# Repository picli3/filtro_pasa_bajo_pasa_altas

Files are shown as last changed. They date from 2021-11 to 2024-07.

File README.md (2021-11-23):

# Filtro pasa medios y pasa altos

Este filtro aun esta en proceso de desarrollo, no me hago responsable de algunos problemas ocacionados, estare subiendo aca los vanaces hasta cerrar el proyecto, eres libre de copiar el proyecto y modificarlo siempre y cuando hagas mension del origen de la informacion.

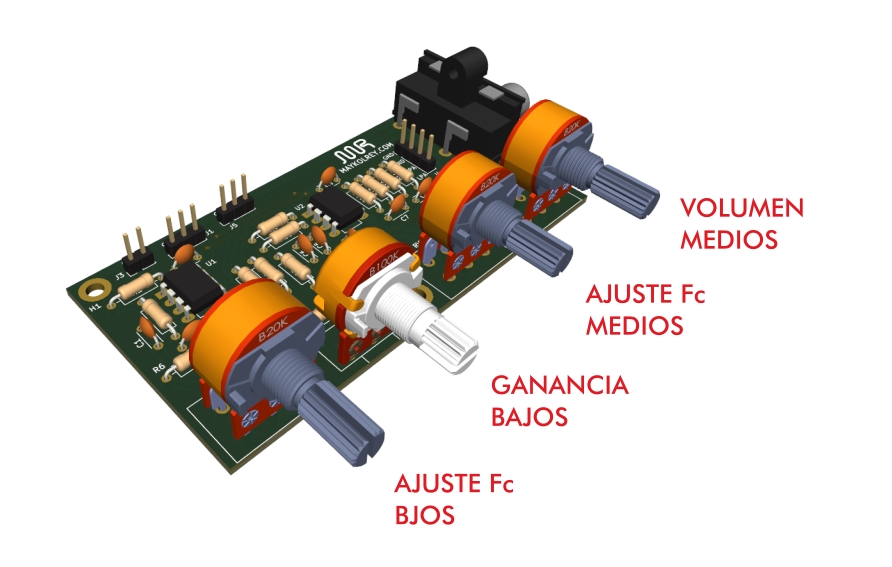
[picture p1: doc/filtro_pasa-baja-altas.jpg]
filtro pasa alta pasa baja filtro

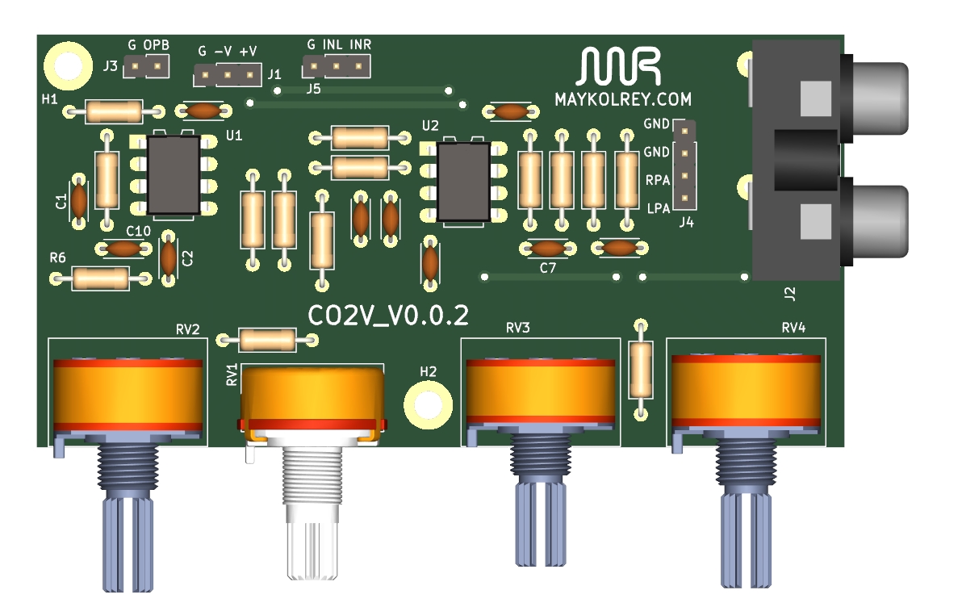
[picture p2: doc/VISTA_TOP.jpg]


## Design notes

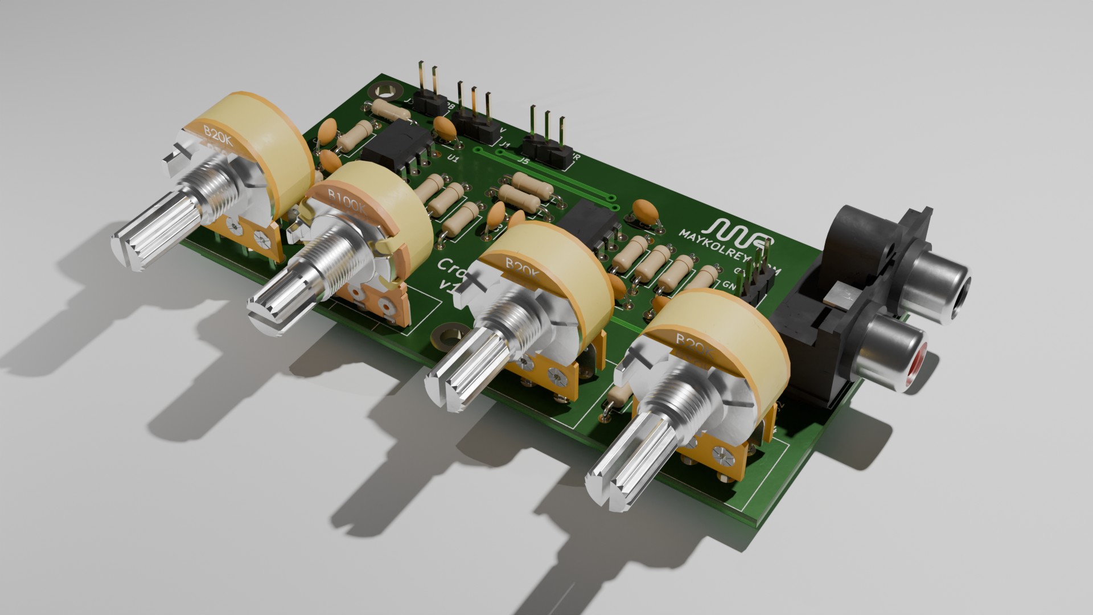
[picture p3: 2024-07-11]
iso.jpg

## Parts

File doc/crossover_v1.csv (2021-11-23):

Item | Qty | Reference(s) | Value | LibPart | Footprint
1 | 6 | C1, C2, C5, C6, C7, C8 | 47nF | Device:C | Capacitor_THT:C_Disc_D4.3mm_W1.9mm_P5.00mm
2 | 4 | C3, C4, C9, C10 | 100nF | Device:C | Capacitor_THT:C_Disc_D4.3mm_W1.9mm_P5.00mm
3 | 2 | H1, H2 | MountingHole | Mechanical:MountingHole | MountingHole:MountingHole_3.2mm_M3_DIN965_Pad
4 | 1 | J1 | POWER | Connector_Generic:Conn_01x03 | Connector_PinHeader_2.54mm:PinHeader_1x03_P2.54mm_Vertical
5 | 1 | J2 | IN | Connector:Conn_Coaxial_x2 | MSS_Connector:CUI_RCJ-21XX
6 | 1 | J3 | OUT | Connector:Conn_01x02_Male | Connector_PinHeader_2.54mm:PinHeader_1x02_P2.54mm_Vertical
7 | 1 | J4 | OUT | Connector:Conn_01x04_Male | Connector_PinHeader_2.54mm:PinHeader_1x04_P2.54mm_Vertical
8 | 1 | J5 | OUT | Connector:Conn_01x03_Male | Connector_PinHeader_2.54mm:PinHeader_1x03_P2.54mm_Vertical
9 | 1 | R1 | 2.7K | Device:R | Resistor_THT:R_Axial_DIN0207_L6.3mm_D2.5mm_P10.16mm_Horizontal
10 | 1 | R2 | 4.7K | Device:R | Resistor_THT:R_Axial_DIN0207_L6.3mm_D2.5mm_P10.16mm_Horizontal
11 | 2 | R3, R4 | 22K | Device:R | Resistor_THT:R_Axial_DIN0207_L6.3mm_D2.5mm_P10.16mm_Horizontal
12 | 4 | R5, R6, R10, R14 | 10K | Device:R | Resistor_THT:R_Axial_DIN0207_L6.3mm_D2.5mm_P10.16mm_Horizontal
13 | 2 | R7, R11 | 1K | Device:R | Resistor_THT:R_Axial_DIN0207_L6.3mm_D2.5mm_P10.16mm_Horizontal
14 | 2 | R8, R12 | 2K | Device:R | Resistor_THT:R_Axial_DIN0207_L6.3mm_D2.5mm_P10.16mm_Horizontal
15 | 2 | R9, R13 | 18K | Device:R | Resistor_THT:R_Axial_DIN0207_L6.3mm_D2.5mm_P10.16mm_Horizontal
16 | 1 | RV1 | 47K | Device:R_Potentiometer | Potentiometer_THT:Potentiometer_Piher_T-16H_Single_Horizontal
17 | 1 | RV2 | 100K | Device:R_Potentiometer_Dual | Potentiometer_THT:Potentiometer_Alps_RK163_Dual_Horizontal
18 | 2 | RV3, RV4 | 5K | Device:R_Potentiometer_Dual | Potentiometer_THT:Potentiometer_Alps_RK163_Dual_Horizontal
19 | 2 | U1, U2 | TL082 | MSS_Operational-Amplifier:TL082 | Package_DIP:DIP-8_W7.62mm_LongPads

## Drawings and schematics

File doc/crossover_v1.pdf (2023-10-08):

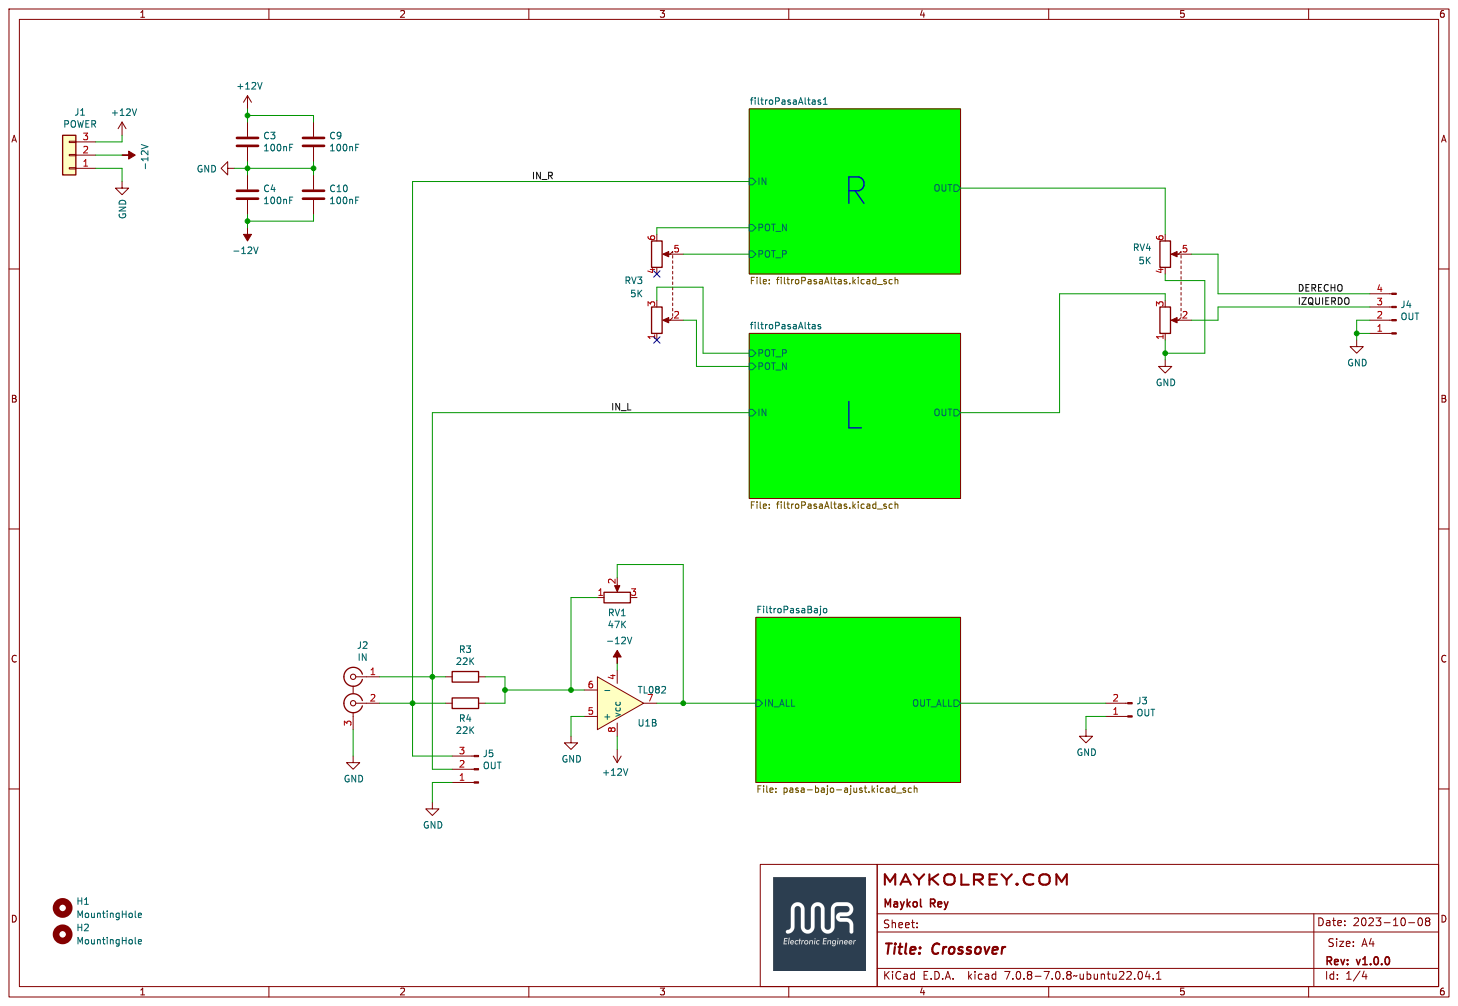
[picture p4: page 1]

MAYKOLREY.COM

Rey | Id: 1/4 Title: Crossover Sheet: Maykol

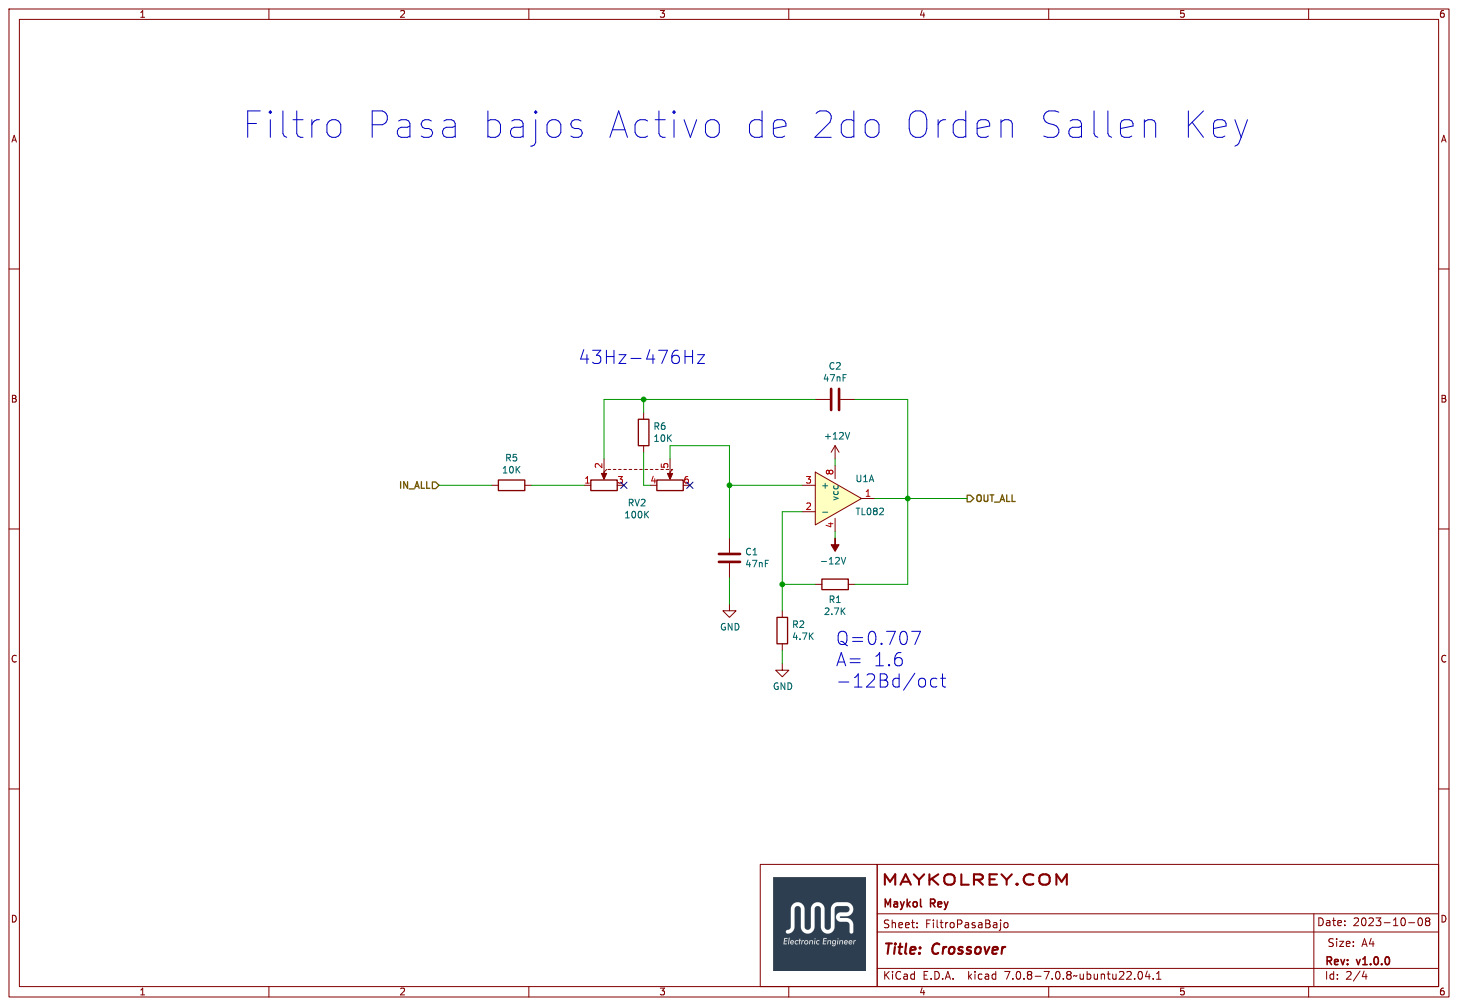
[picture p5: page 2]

Id: 2/4 Title: Crossover Sheet: FiltroPasaBajo

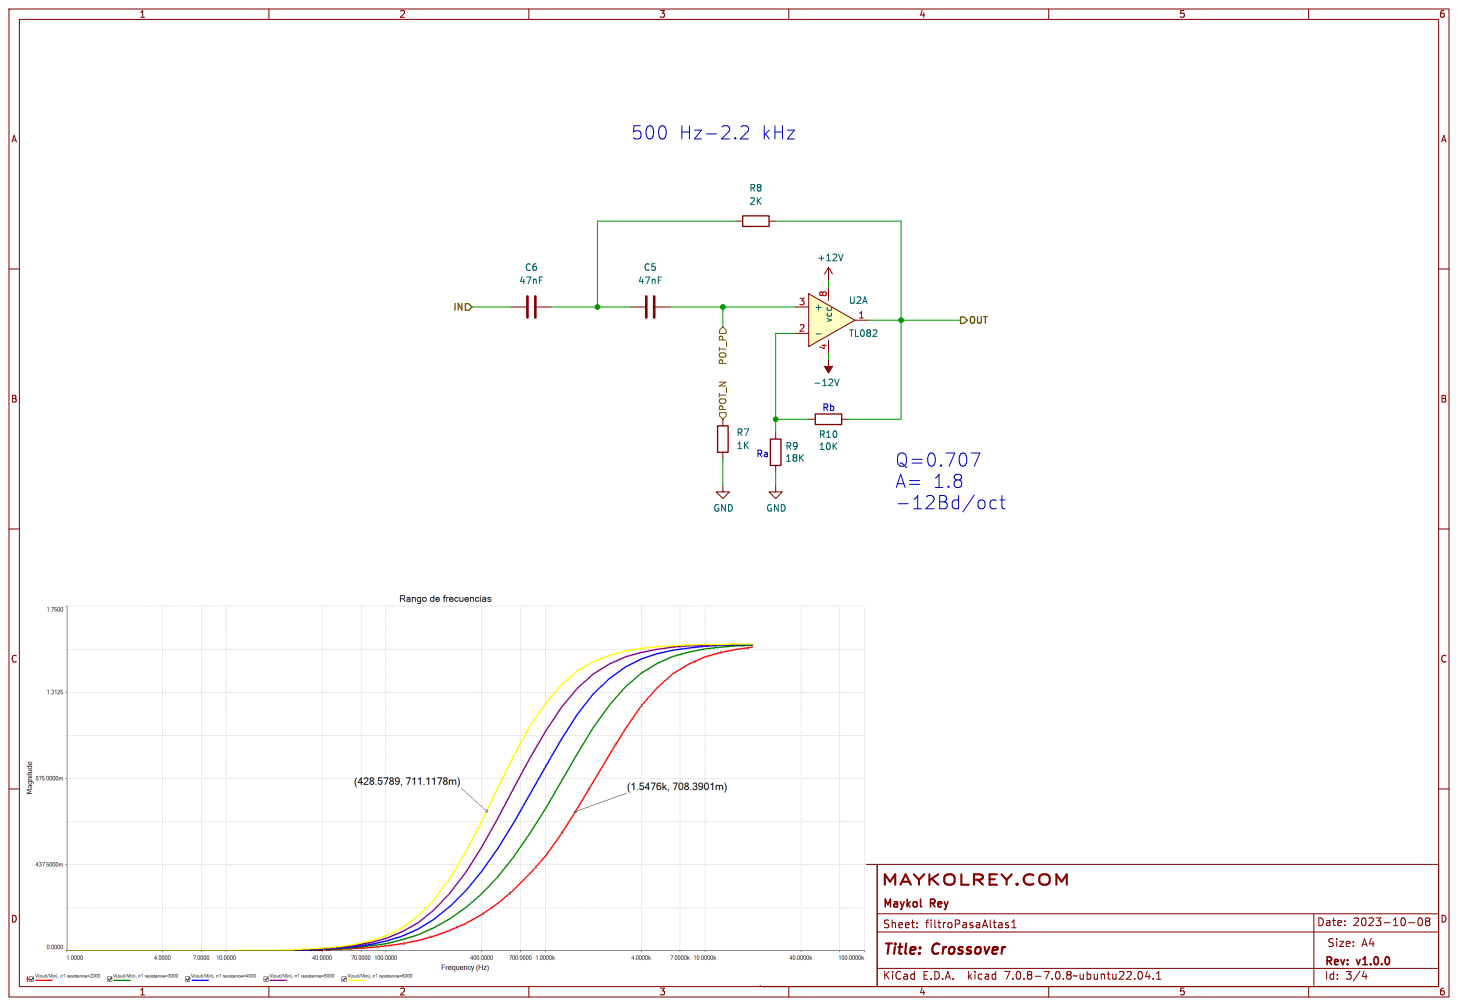
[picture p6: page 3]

MAYKOLREY.COM

Rey | Id: 3/4 Title: Crossover Sheet: filtroPasaAltas1 Maykol

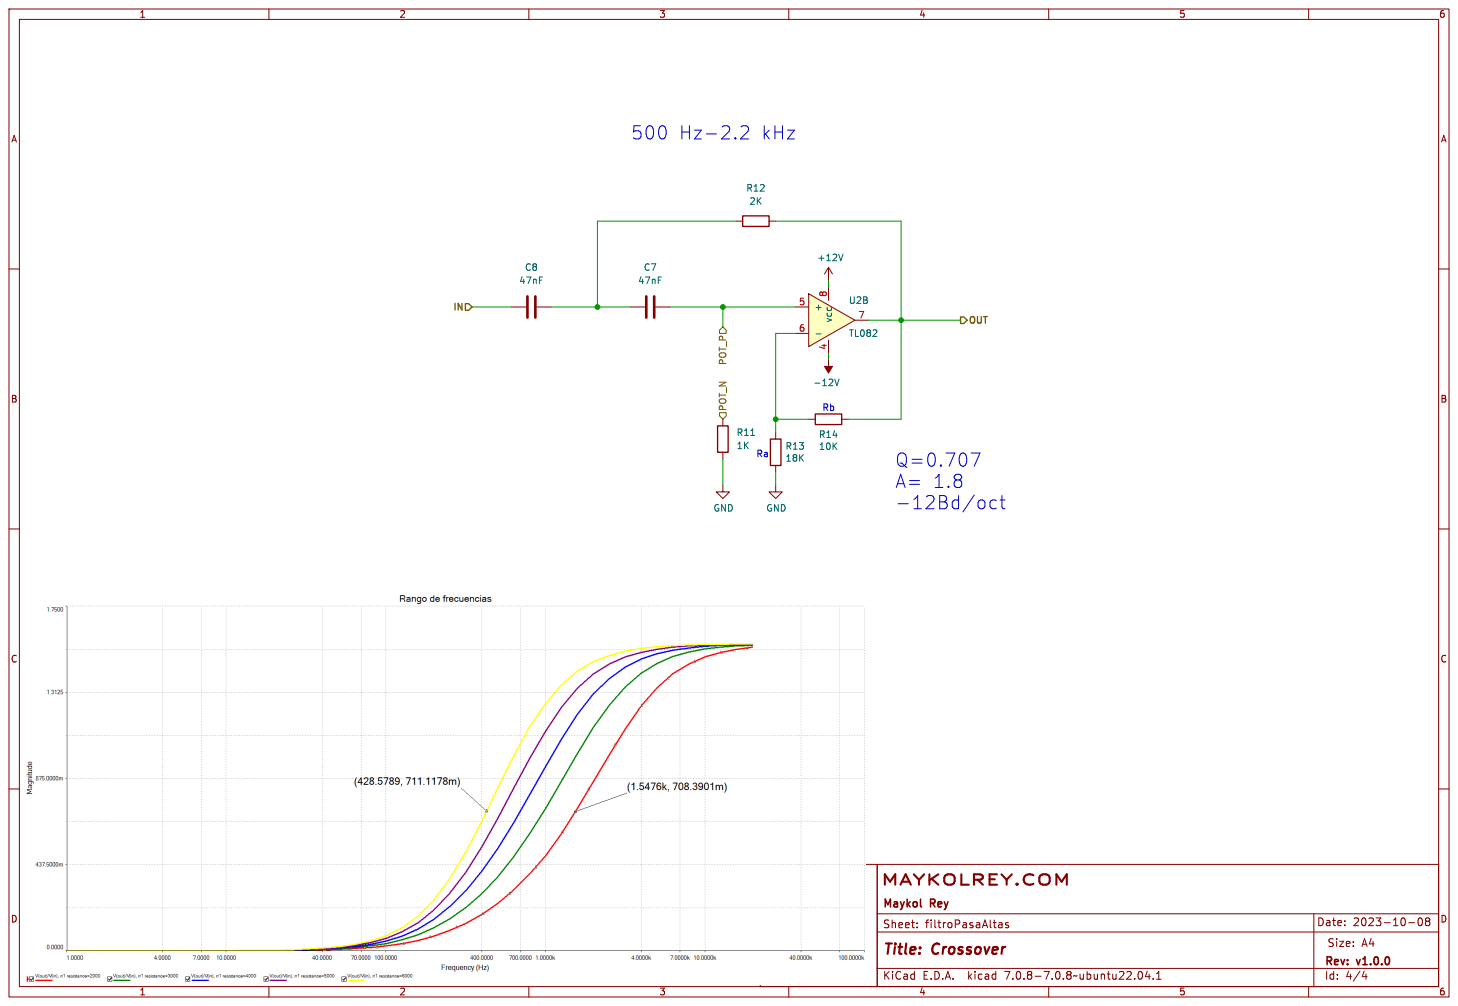
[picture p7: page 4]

MAYKOLREY.COM

Rey | Id: 4/4 Title: Crossover Sheet: filtroPasaAltas Maykol

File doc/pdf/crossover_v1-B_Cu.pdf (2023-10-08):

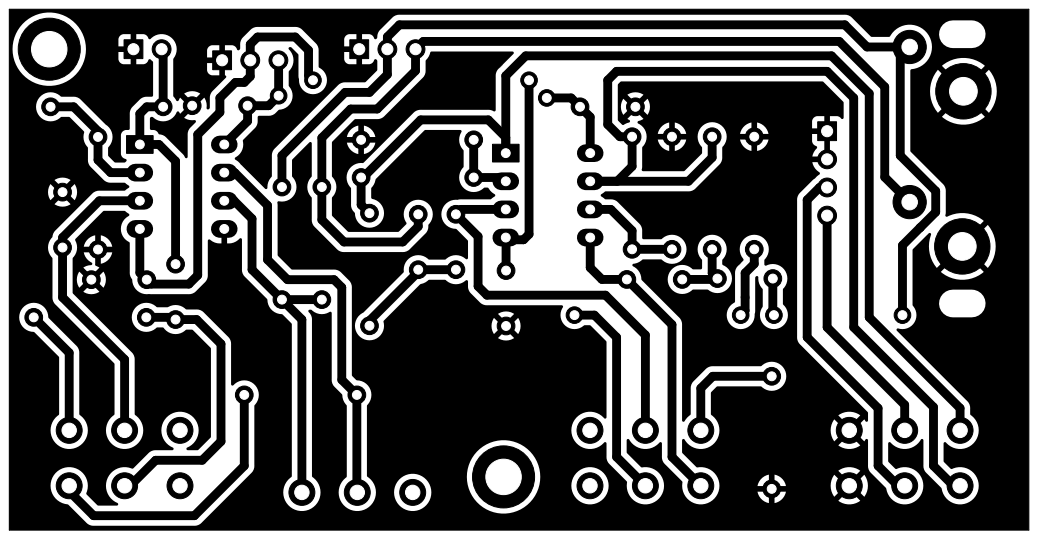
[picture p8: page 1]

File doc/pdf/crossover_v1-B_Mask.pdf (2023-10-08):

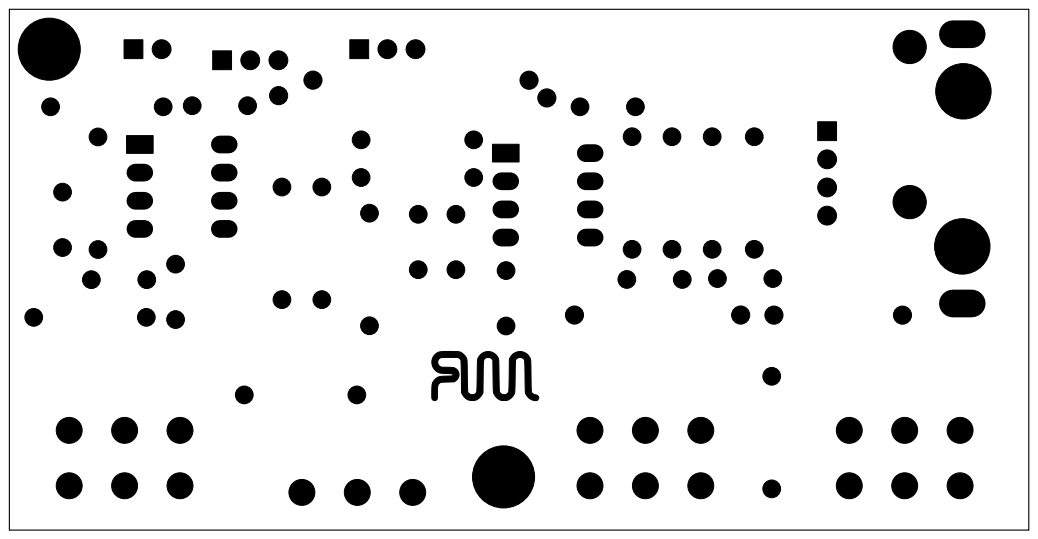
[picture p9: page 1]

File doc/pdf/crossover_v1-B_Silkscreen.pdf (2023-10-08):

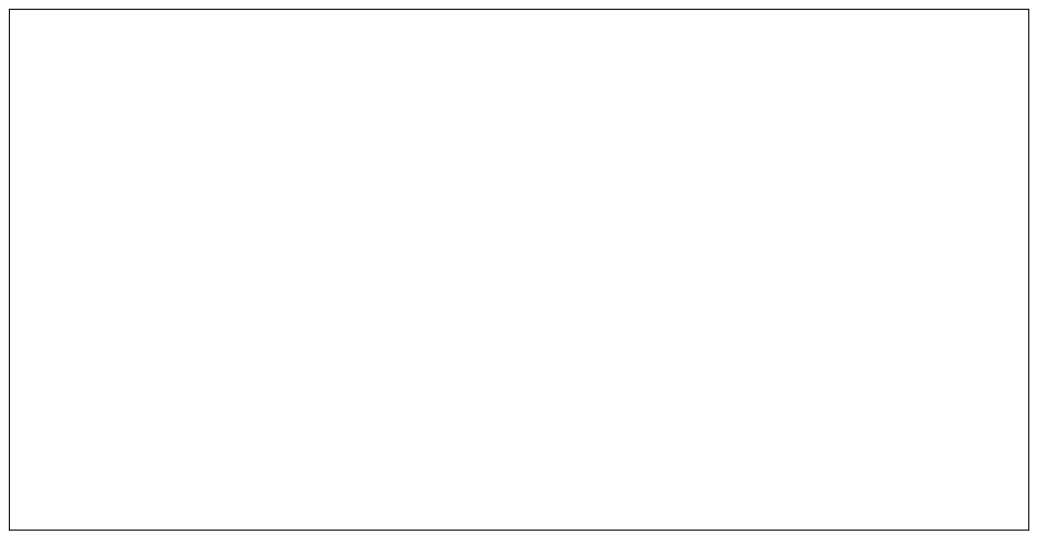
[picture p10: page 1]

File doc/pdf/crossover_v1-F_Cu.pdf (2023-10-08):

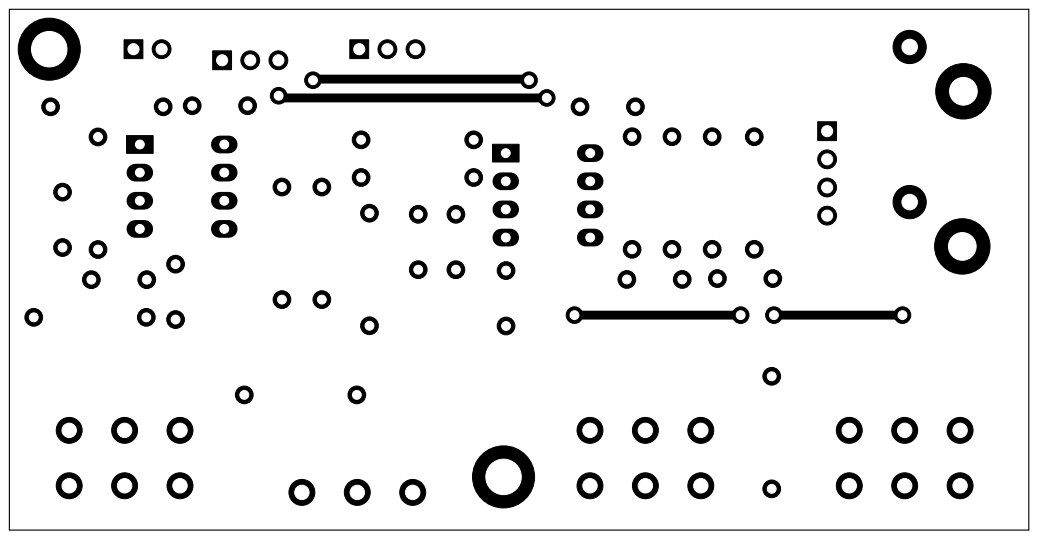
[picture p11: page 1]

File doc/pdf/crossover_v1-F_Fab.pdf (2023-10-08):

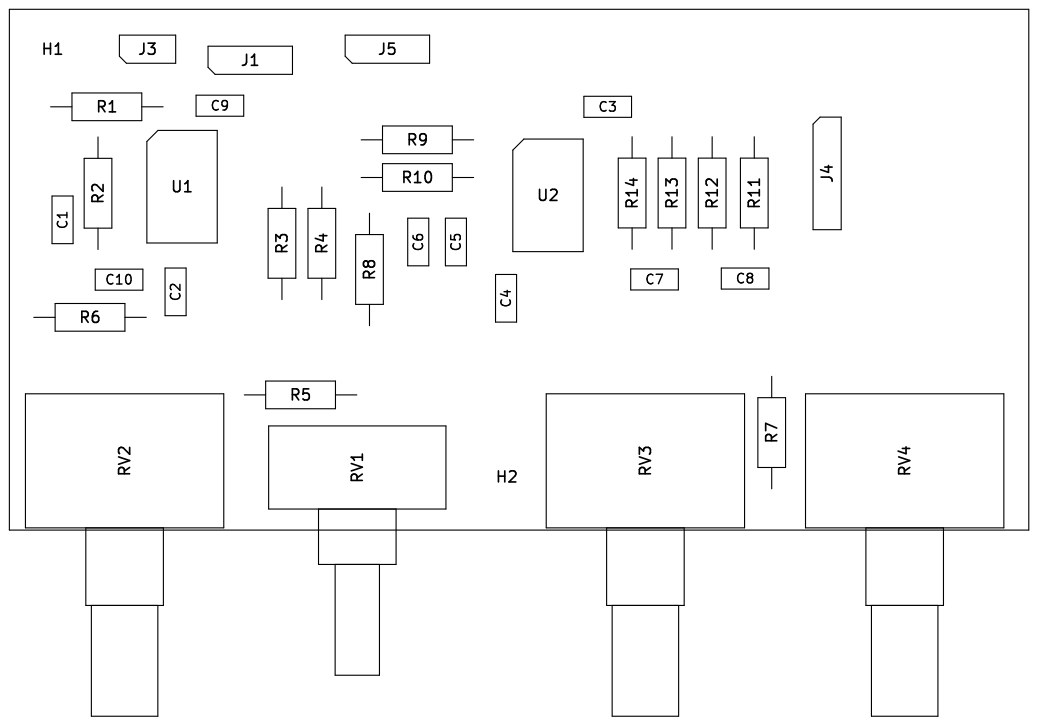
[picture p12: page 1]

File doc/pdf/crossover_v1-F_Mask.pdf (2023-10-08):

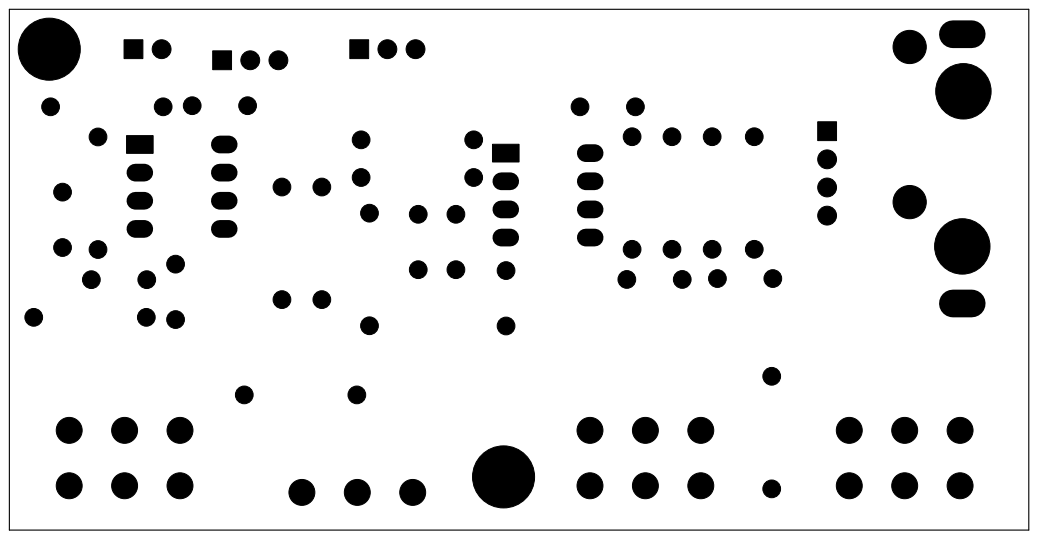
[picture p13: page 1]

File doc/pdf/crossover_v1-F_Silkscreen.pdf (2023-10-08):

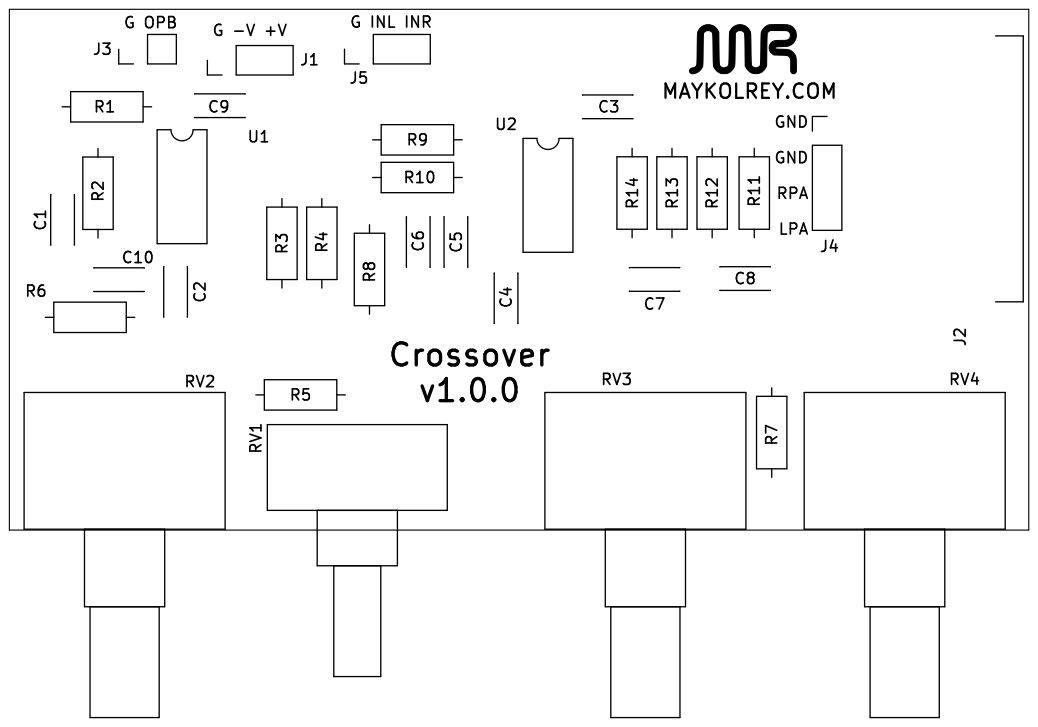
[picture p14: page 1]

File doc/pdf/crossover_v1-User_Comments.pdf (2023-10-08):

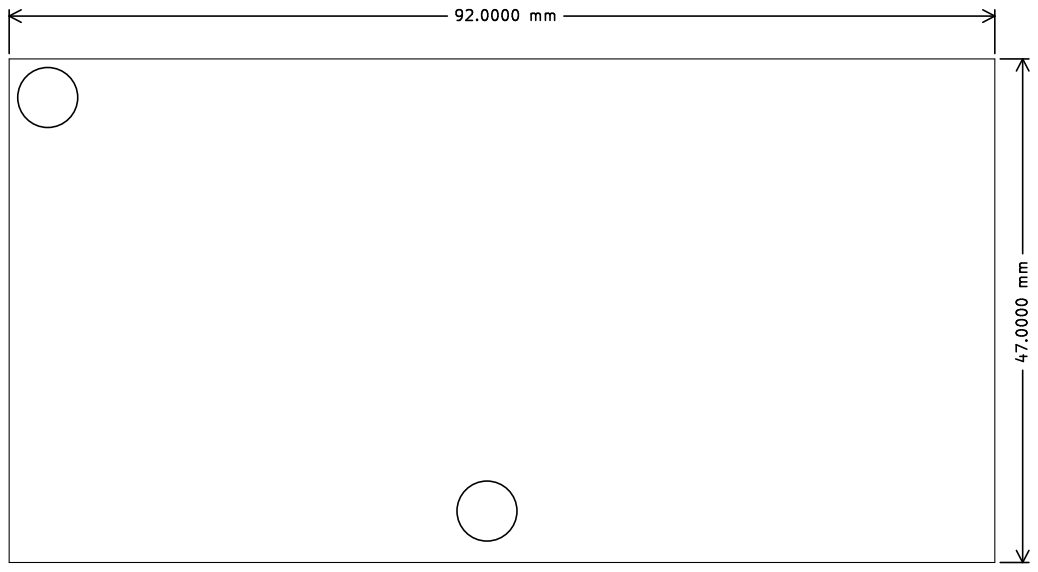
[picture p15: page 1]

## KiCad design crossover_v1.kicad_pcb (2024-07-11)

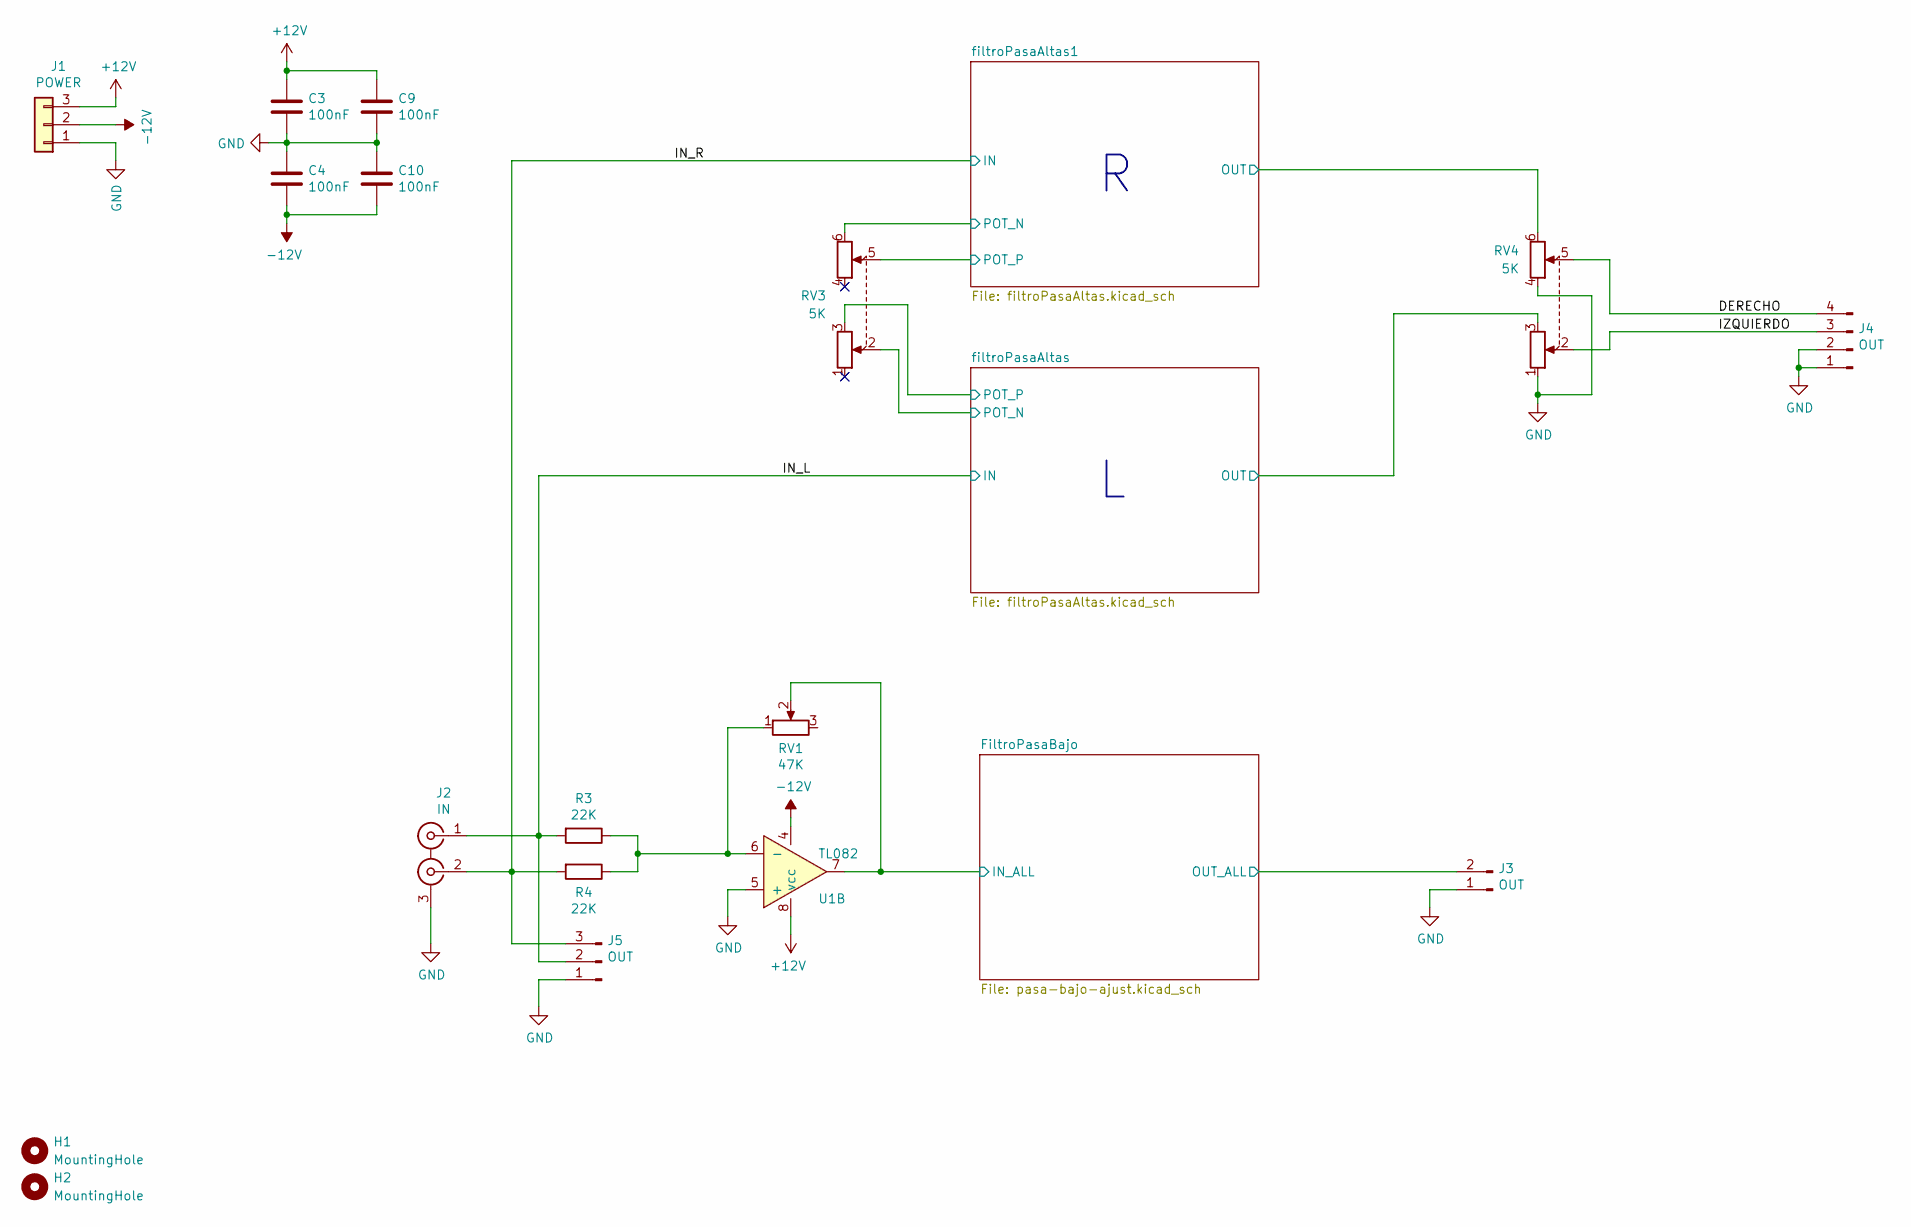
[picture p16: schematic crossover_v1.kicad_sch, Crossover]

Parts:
C3, C4, C9, C10: 100nF; C_Disc_D4.3mm_W1.9mm_P5.00mm
H1, H2: MountingHole; MountingHole_3.2mm_M3_DIN965_Pad
J1: POWER; PinHeader_1x03_P2.54mm_Vertical
J2: IN; CUI_RCJ-21XX
J3: OUT; PinHeader_1x02_P2.54mm_Vertical
J4: OUT; PinHeader_1x04_P2.54mm_Vertical
J5: OUT; PinHeader_1x03_P2.54mm_Vertical
R3, R4: 22K; R_Axial_DIN0207_L6.3mm_D2.5mm_P10.16mm_Horizontal
RV1: 47K; Potentiometer_Piher_T-16H_Single_Horizontal
RV3, RV4: 5K; Potentiometer_Alps_RK163_Dual_Horizontal
U1: TL082; DIP-8_W7.62mm_LongPads

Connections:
+12V: C3.2, C9.2, J1.3, U1.8 (vcc); also elsewhere on the board
-12V: C4.1, C10.1, J1.2, U1.4; also elsewhere on the board
/DERECHO: J4.4, RV4.5
/FiltroPasaBajo/IN_ALL: RV1.2, U1.7; also elsewhere on the board
/FiltroPasaBajo/OUT_ALL: J3.2; also elsewhere on the board
/IN_L: J2.1 (IN1), J5.2, R3.2; also elsewhere on the board
/IN_R: J2.2 (IN2), J5.3, R4.2; also elsewhere on the board
/IZQUIERDO: J4.3, RV4.2
/filtroPasaAltas1/OUT: RV4.6; also elsewhere on the board
/filtroPasaAltas1/POT_N: RV3.6; also elsewhere on the board
/filtroPasaAltas1/POT_P: RV3.5; also elsewhere on the board
/filtroPasaAltas/OUT: RV4.3; also elsewhere on the board
/filtroPasaAltas/POT_N: RV3.2; also elsewhere on the board
/filtroPasaAltas/POT_P: RV3.3; also elsewhere on the board
GND: C3.1, C4.2, C9.1, C10.2, J1.1, J2.3 (EXT), J3.1, J4.1, J4.2, J5.1, RV4.1, RV4.4, U1.5 (+); also elsewhere on the board
unnamed: R3.1, R4.1, RV1.1, U1.6 (-)

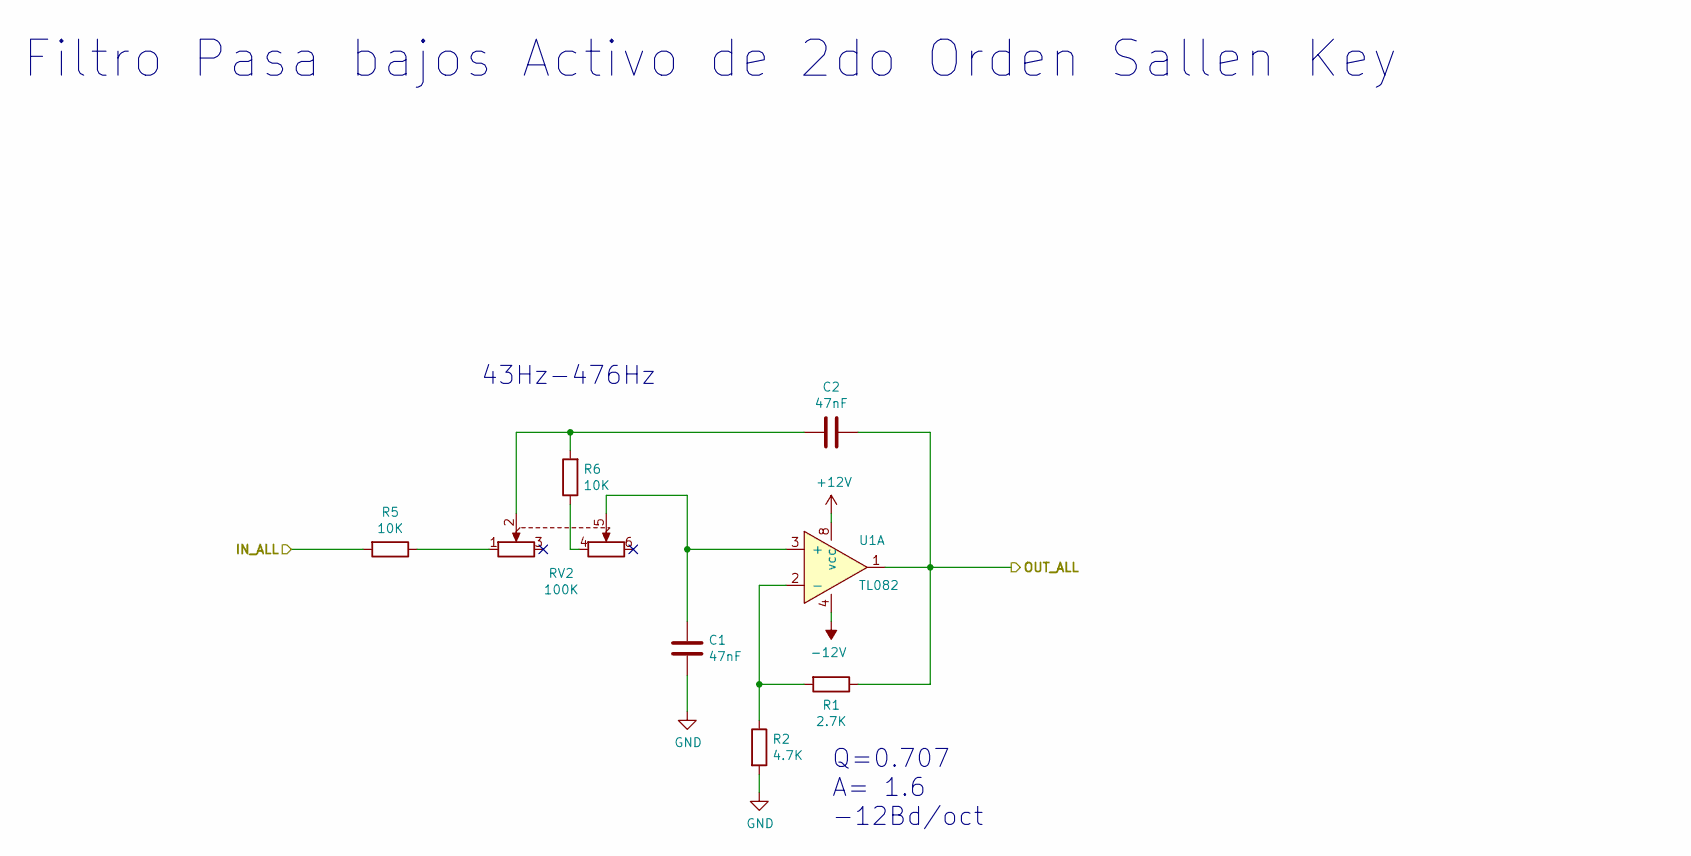
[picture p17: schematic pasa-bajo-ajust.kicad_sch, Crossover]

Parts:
C1, C2: 47nF; C_Disc_D4.3mm_W1.9mm_P5.00mm
R1: 2.7K; R_Axial_DIN0207_L6.3mm_D2.5mm_P10.16mm_Horizontal
R2: 4.7K; R_Axial_DIN0207_L6.3mm_D2.5mm_P10.16mm_Horizontal
R5, R6: 10K; R_Axial_DIN0207_L6.3mm_D2.5mm_P10.16mm_Horizontal
RV2: 100K; Potentiometer_Alps_RK163_Dual_Horizontal
U1: TL082; DIP-8_W7.62mm_LongPads

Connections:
+12V: U1.8 (vcc); also elsewhere on the board
-12V: U1.4; also elsewhere on the board
/FiltroPasaBajo/IN_ALL: R5.2; also elsewhere on the board
/FiltroPasaBajo/OUT_ALL: C2.1, R1.1, U1.1; also elsewhere on the board
GND: C1.1, R2.2; also elsewhere on the board
unnamed: C1.2, RV2.5, U1.3 (+)
unnamed: C2.2, R6.2, RV2.2
unnamed: R1.2, R2.1, U1.2 (-)
unnamed: R5.1, RV2.1
unnamed: R6.1, RV2.4

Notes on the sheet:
Filtro Pasa bajos Activo de 2do Orden Sallen Key
Q=0.707 A= 1.6 -12Bd/oct
43Hz-476Hz

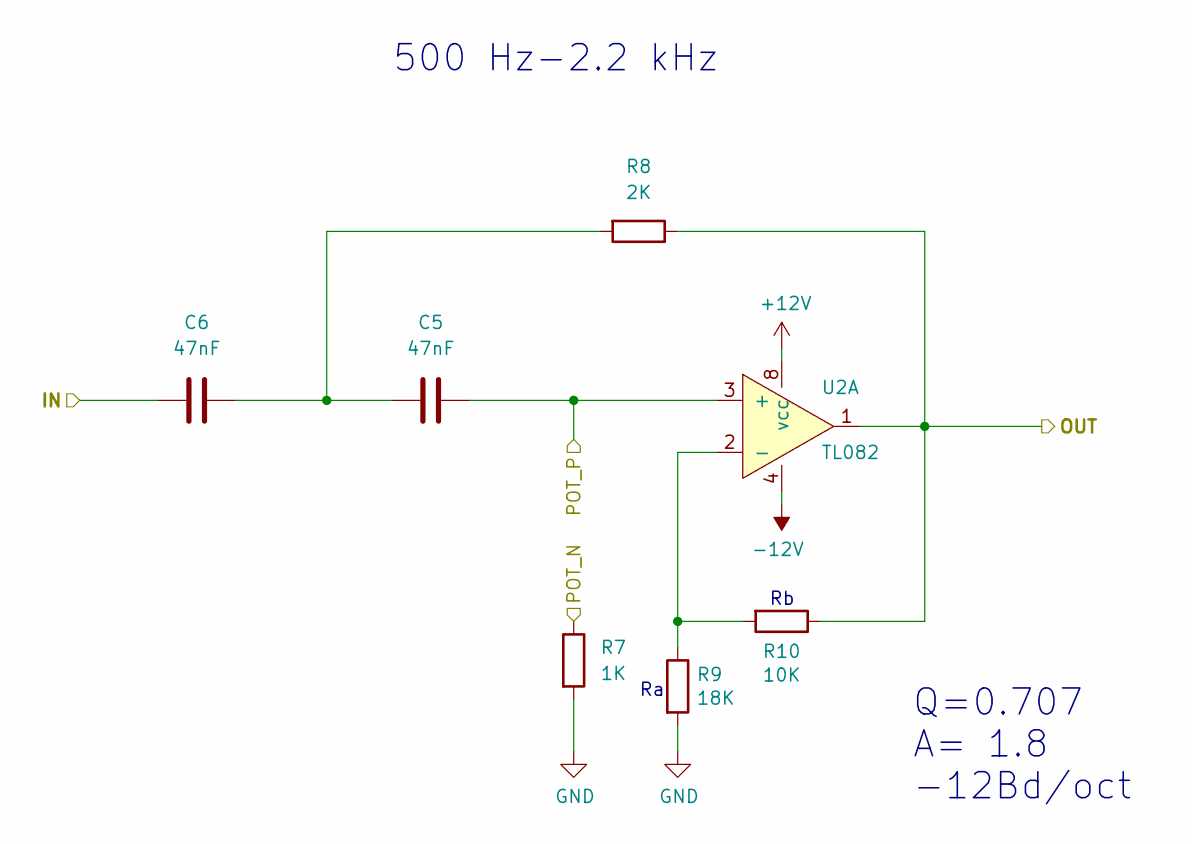
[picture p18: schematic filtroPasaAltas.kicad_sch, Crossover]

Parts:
C5, C6: 47nF; C_Disc_D4.3mm_W1.9mm_P5.00mm
R7: 1K; R_Axial_DIN0207_L6.3mm_D2.5mm_P10.16mm_Horizontal
R8: 2K; R_Axial_DIN0207_L6.3mm_D2.5mm_P10.16mm_Horizontal
R9: 18K; R_Axial_DIN0207_L6.3mm_D2.5mm_P10.16mm_Horizontal
R10: 10K; R_Axial_DIN0207_L6.3mm_D2.5mm_P10.16mm_Horizontal
U2: TL082; DIP-8_W7.62mm_LongPads

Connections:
+12V: U2.8 (vcc); also elsewhere on the board
-12V: U2.4; also elsewhere on the board
/IN_R: C6.2; also elsewhere on the board
/filtroPasaAltas1/OUT: R8.1, R10.1, U2.1; also elsewhere on the board
/filtroPasaAltas1/POT_N: R7.1; also elsewhere on the board
/filtroPasaAltas1/POT_P: C5.1, U2.3 (+); also elsewhere on the board
/filtroPasaAltas/OUT: U2.7; also elsewhere on the board
/filtroPasaAltas/POT_P: U2.5 (+); also elsewhere on the board
GND: R7.2, R9.2; also elsewhere on the board
unnamed: C5.2, C6.1, R8.2
unnamed: R9.1, R10.2, U2.2 (-)
unnamed 24: U2.6 (-); also elsewhere on the board

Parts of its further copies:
C7, C8: 47nF; C_Disc_D4.3mm_W1.9mm_P5.00mm
R11: 1K; R_Axial_DIN0207_L6.3mm_D2.5mm_P10.16mm_Horizontal
R12: 2K; R_Axial_DIN0207_L6.3mm_D2.5mm_P10.16mm_Horizontal
R13: 18K; R_Axial_DIN0207_L6.3mm_D2.5mm_P10.16mm_Horizontal
R14: 10K; R_Axial_DIN0207_L6.3mm_D2.5mm_P10.16mm_Horizontal

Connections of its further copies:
/IN_L: C8.2; also elsewhere on the board
/filtroPasaAltas/OUT: R12.1, R14.1; also elsewhere on the board
/filtroPasaAltas/POT_N: R11.1; also elsewhere on the board
/filtroPasaAltas/POT_P: C7.1; also elsewhere on the board
GND: R11.2, R13.2; also elsewhere on the board
unnamed: C7.2, C8.1, R12.2
unnamed 24: R13.1, R14.2; also elsewhere on the board

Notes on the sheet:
Q=0.707 A= 1.8 -12Bd/oct
500 Hz-2.2 kHz

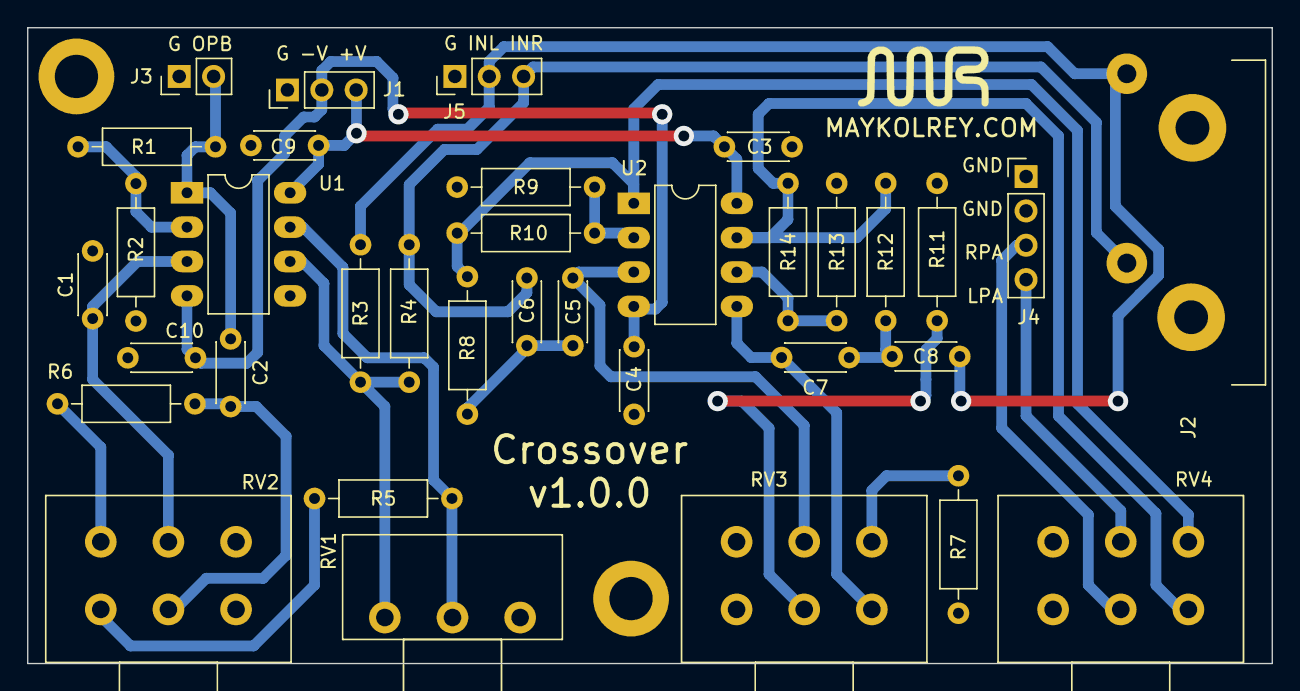
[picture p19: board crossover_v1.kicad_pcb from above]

Board: 2 copper layers, 92.0 x 47.0 mm, 37 parts (0 on the bottom side), 25 nets.

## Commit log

2021-11-12 agregando el primer commit, proyecto sin probar
    [crossover_v1.csv, crossover_v1.kicad_pcb, crossover_v1.kicad_sch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]
2021-11-23 agregando control de volumen de medios, corrigiendo espacio de potenciometro doble
    [crossover_v1-B_Cu.gbr, crossover_v1-B_Mask.gbr, crossover_v1-B_Paste.gbr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]
2021-11-26 Create License
    Se agrega licencia GPL para que el proyecto se pueda distribuir bajo los conceptos de la misma licencia
2023-10-08 agregando archivos pdf
    [crossover_v1-B_Cu.gbr, crossover_v1-B_Fab.gbr, crossover_v1-B_Mask.gbr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]
2024-07-11 cambiando a kicad 8
    [crossover_v1.kicad_pcb, crossover_v1.kicad_sch, filtroPasaAltas.kicad_sch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]
2025-01-30 cambiando la forma de los archivos del sistema
    [crossover_v1-B_Cu.gbr, crossover_v1-B_Mask.gbr, crossover_v1-B_Paste.gbr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]
